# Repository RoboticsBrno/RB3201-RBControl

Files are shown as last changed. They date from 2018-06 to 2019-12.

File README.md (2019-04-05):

# RB3201-RBControl

[[English version follows]](#english-version)

RB3201-RBControl (RBC) - univerzální deska pro stavbu hobby robotů.

Licence: [CC BY-SA 4.0](https://creativecommons.org/licenses/by-sa/4.0/?)

Arduino knihovna: [RB3201-RBControl-library](https://github.com/RoboticsBrno/RB3201-RBControl-library) ([PlatformIO](https://platformio.org/lib/show/5532/RB3201-RBControl))

Jde v podstatě o shield k vývojovému kitu [ESP32-DevKitC](https://www.espressif.com/en/products/hardware/esp32-devkitc/overview), který má dva hlavní cíle:

- umožnit snadné připojení velkého množství různých periférií (motory s enkodéry, serva, senzory...)
- rozšířit počet pinů desky ESP32 

## Hlavní vlastnosti

- současně ovládat až 8 DC motorů (1,5 A trvale, 2A špičkově každý) a obsluhovat 8 enkodérů pro tyto motory
- po osazení spínanými zdroji napájet a ovládat 4 serva nebo 8 mikroserv
- vyvedená I2C sběrnice - celkem 6x (4x s 3,3 V a 2x s 5 V logickou úrovní)
- expandér pinů, který je připojený přes I2C a obsluhuje další dva porty A,B po 8 pinech (celkem dalších 16 pinů) 
- tři tlačítka, 4 LED a piezo
- připravena ochrana proti přepólování a podvybití

## Rozšiřující moduly

### Motor enkodér

DPS jako enkodér na [upravené levné čínské motory s magnetem](https://mickoflus.cz/guide.html#motor-magnet)

- [Schema](docs/RB3201-RBControl_MotorEncoder_v1.1_schema.png)
- [Board](docs/RB3201-RBControl_MotorEncoder_v1.1_board.png)

### Lego konektor

- [LegoConnectorX1A - Schema](docs/RB3201-RBControl_LegoConnectorX1A_v1.0_schema.png)
- [LegoConnectorX1A - Board](docs/RB3201-RBControl_LegoConnectorX1A_v1.0_board.png)
- [LegoConnectorX1B - Schema](docs/RB3201-RBControl_LegoConnectorX1B_v1.0_schema.png)
- [LegoConnectorX1B - Board](docs/RB3201-RBControl_LegoConnectorX1B_v1.0_board.png)
- [LegoConnectorX2 - Schema](docs/RB3201-RBControl_LegoConnectorX2_v1.0_schema.png)
- [LegoConnectorX2 - Board](docs/RB3201-RBControl_LegoConnectorX2_v1.0_board.png)

# English Version

RB3201-RBControl (RBC) is a universal controller for hobby robots.

License: [CC BY-SA 4.0](https://creativecommons.org/licenses/by-sa/4.0/?)

Arduino library: [RB3201-RBControl-library](https://github.com/RoboticsBrno/RB3201-RBControl-library) ([PlatformIO](https://platformio.org/lib/show/5532/RB3201-RBControl))

The board is a shield for [ESP32-DevKitC](https://www.espressif.com/en/products/hardware/esp32-devkitc/overview) with the following two main functions:

- the board allows connecting a variety of peripherals (DC motors with encoders, RC servo motors, sensors, etc...)
- it expands the ESP32 GPIOs.

## Main Features

- it can control up to 8 DC motors (1.5 A average, 2 A peak for each motor), possibly with an encoder for each motor;
- after populating switching power supplies, it can power and control 4 servo motors or 8 micro servo motors;
- there are I2C headers for connection up to 6 peripherals (4x 3.3V, 2x 5V);
- there is an I2C GPIO expander, which adds two ports (A and B), 8 GPIOs each;
- three push buttons, four LEDs and a piezo buzzer built-in;
- reverse polarity and over-discharge protection.

## Expanding modules

### MotorEncoder

PCB encoder for dirty cheap Chinese DC motors with encoders.

- [Schema](docs/RB3201-RBControl_MotorEncoder_v1.1_schema.png)
- [Board](docs/RB3201-RBControl_MotorEncoder_v1.1_board.png)

### LegoConnector

- [LegoConnectorX1A - Schema](docs/RB3201-RBControl_LegoConnectorX1A_v1.0_schema.png)
- [LegoConnectorX1A - Board](docs/RB3201-RBControl_LegoConnectorX1A_v1.0_board.png)
- [LegoConnectorX1B - Schema](docs/RB3201-RBControl_LegoConnectorX1B_v1.0_schema.png)
- [LegoConnectorX1B - Board](docs/RB3201-RBControl_LegoConnectorX1B_v1.0_board.png)
- [LegoConnectorX2 - Schema](docs/RB3201-RBControl_LegoConnectorX2_v1.0_schema.png)
- [LegoConnectorX2 - Board](docs/RB3201-RBControl_LegoConnectorX2_v1.0_board.png)

## Schema ([PDF](docs/RB3201-RBControl_MainBoard_v1.2_schema.pdf))

Logic
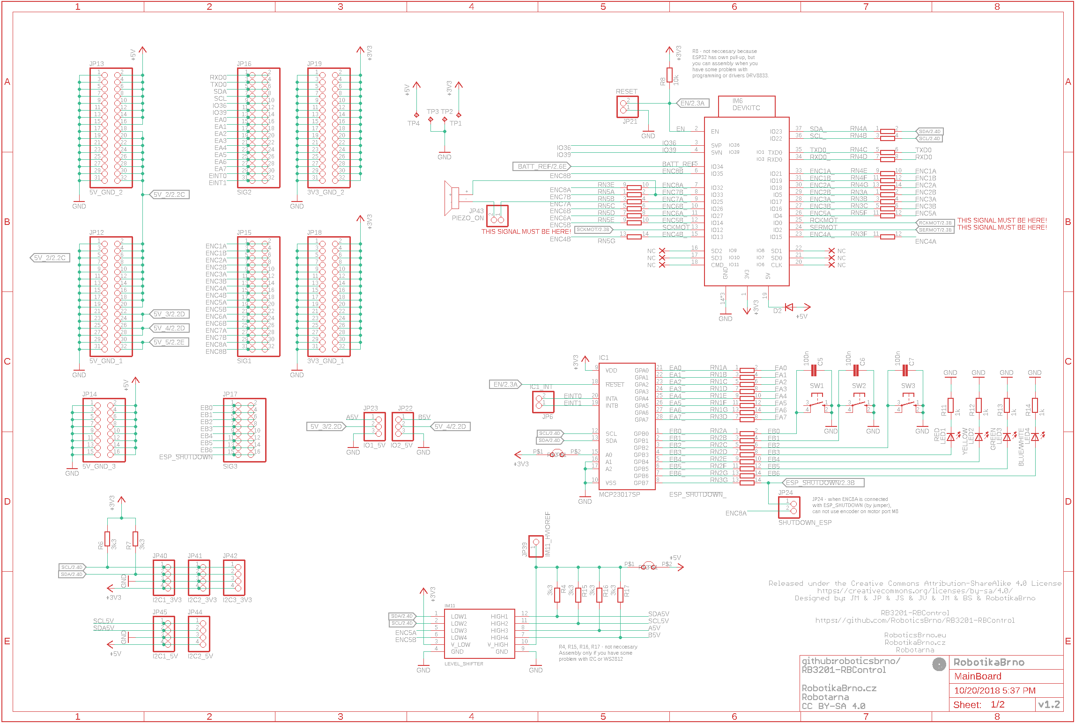
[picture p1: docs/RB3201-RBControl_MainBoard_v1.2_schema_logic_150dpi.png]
RB3201-RBControl - schema logic


Power
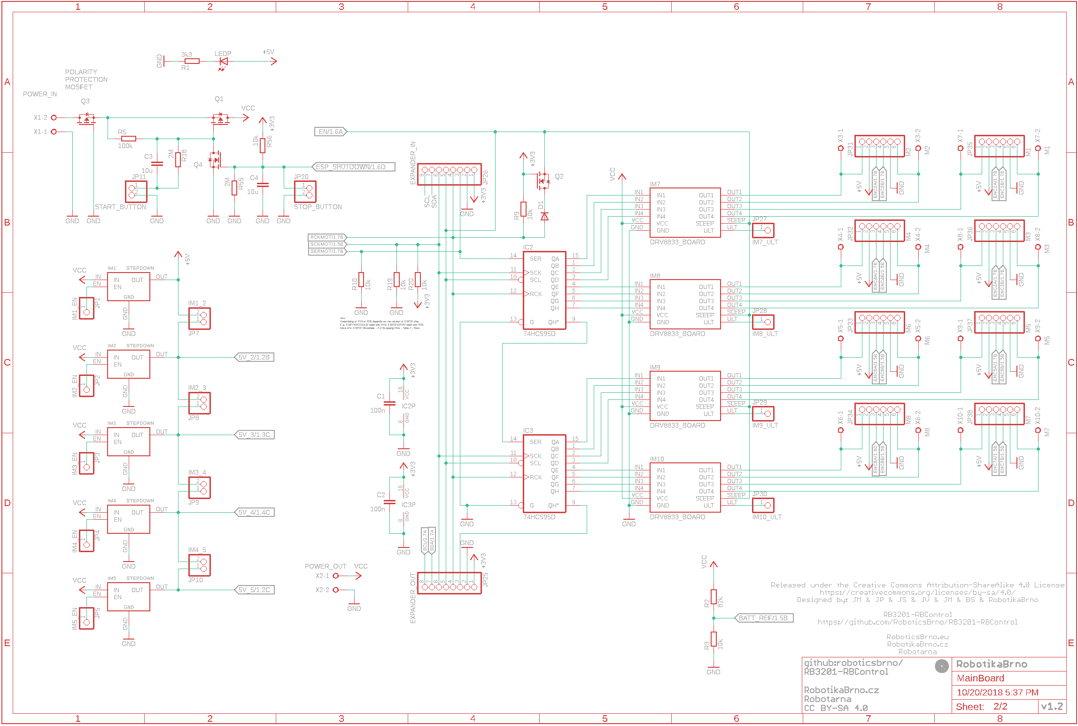
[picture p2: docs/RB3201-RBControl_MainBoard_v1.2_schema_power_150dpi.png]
RB3201-RBControl - schema power


## PCB ([PDF](docs/RB3201-RBControl_MainBoard_v1.2_board.pdf))

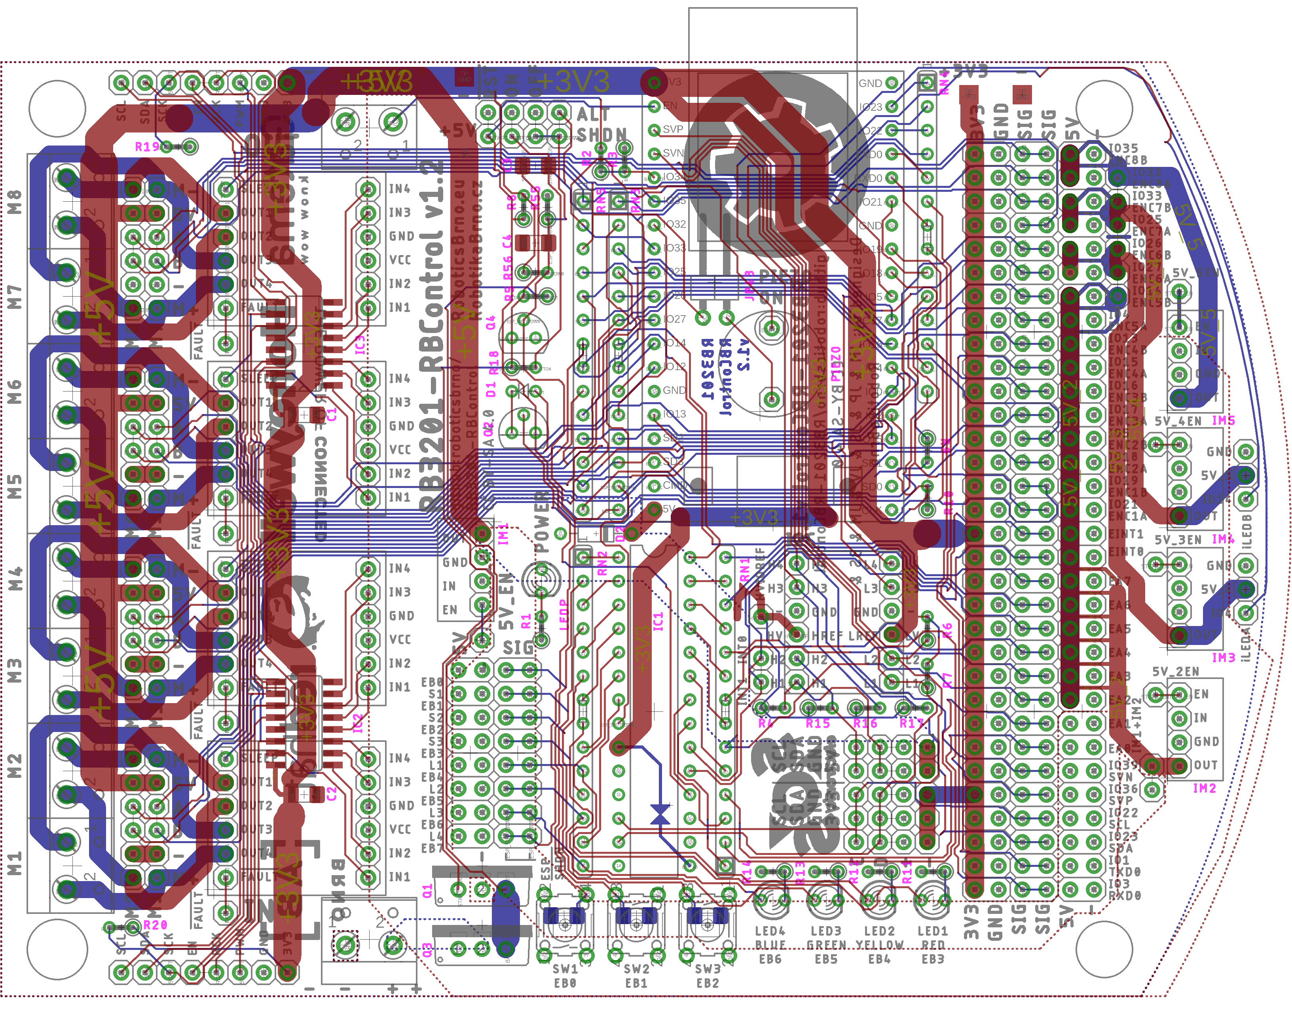
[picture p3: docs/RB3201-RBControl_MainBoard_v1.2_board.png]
RB3201-RBControl - PCB


## Photos

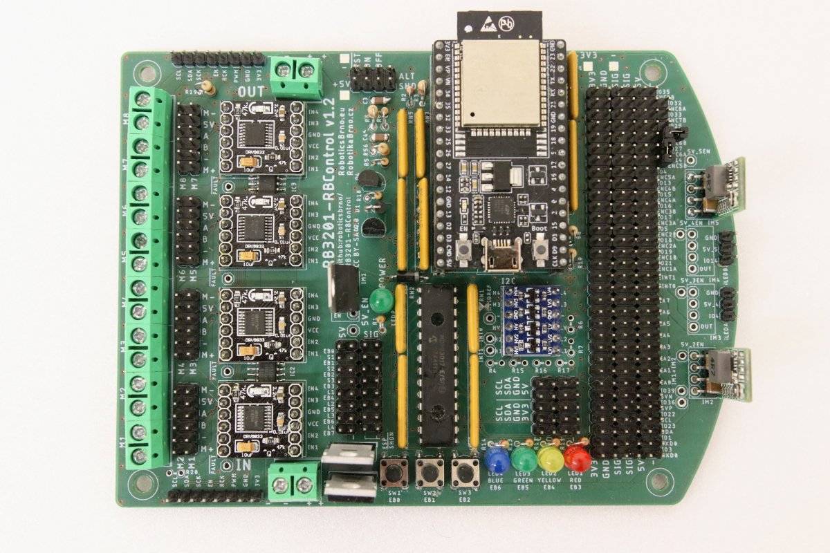
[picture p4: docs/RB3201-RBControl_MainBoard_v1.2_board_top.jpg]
RB3201-RBControl - PCB photo - top


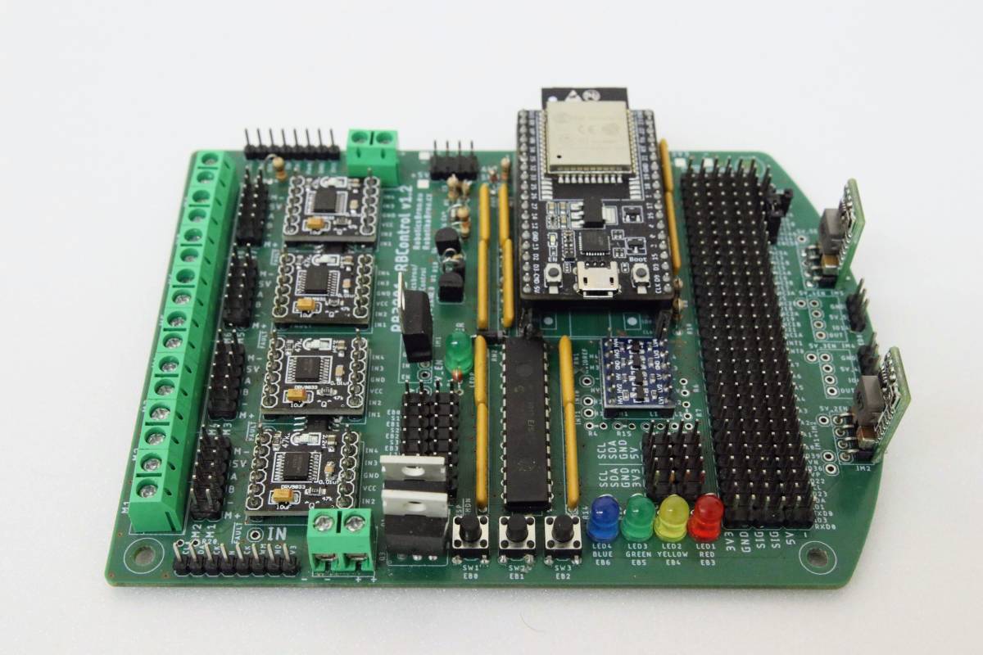
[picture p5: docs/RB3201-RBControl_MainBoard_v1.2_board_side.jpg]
RB3201-RBControl - PCB photo - side


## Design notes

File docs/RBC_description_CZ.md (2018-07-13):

# Vlastnosti desky RB3201-RBControl

## Určení a cíl

RB3201 - RBControl (RBC) je univerzální deska pro stavbu hobby robotů. Jde v podstatě o shield k desce 
 [ESP32 dev kit](https://www.espressif.com/en/products/hardware/esp32-devkitc/overview), který má dva hlavní cíle: rozšířit počet pinů desky ESP32 a umožnit snadné připojení velkého množství různých periférií. 

## Hlavní vlastnosti 

Deska RBC umožňuje současně ovládat až 8 DC motorů (1,5 	  A trvale, 2A špičkově každý). Dále umí po osazení spínanými zdroji napájet a ovládat 4 serva nebo 8 mikroserv. Má vyvedenou I2C sběrnici celkem 6x na 3,3 	  V a 2x na 5 	  V. Dále je na desce expandér pinů, který je připojený na I2C a obsluhuje další dva porty A,B po 8 pinech. Na desce jsou vyvedená tři tlačítka, 4 LED a piezo. 

## Další vlastnosti 

Po osazení tranzistorem Q3 je deska chráněná proti přepólování. Přímo na desce je možné měřit reálné hodnoty napětí 3,3 	  V a
5 	  V rozvedených po desce. 

Čip ESP32 má 26 použitelných pinů, z toho 4 pouze vstupní. Přitom na dvou pinech je připojena sériová linka (používá se pro programování čipu přes USB), na dvou pinech je I2C, 3 piny jsou použity pro komunikaci s drivery pro motory, 1 pin měří napětí na baterii. Pro uživatele tedy zbývá 14 pinů. 

K RBC s ESP32 je možné připojit další RBC bez ESP32 a rozšířit tak počet periférií a počet ovládaných motorů. U motorů na připojené ovládané RBC desce nelze použít enkodéry. Také je možné připojit k I2C místo 5 	  V libovolné externí napětí do cca 30 	  V  a provozovat I2C na tomto napětí. 

## Napájení

Napájení desky RBC je ideální ze dvou Li-On baterií, které dodávají asi 8 	  V a dostatečné proudy. K desce lze připojit napětí až do 10 	  V, připojení vyššího napětí neumožňují použité drivery pro motory. Do motorů je přiváděn signál PWM na napětí z baterie a 5 	  V napájení pro enkodéry.  

RBC si hlídá napětí na baterii a umí ho měřit do 10 	  V. 
V ESP32 je softwarově (v knihovně) nastavené napětí napájení 7,2 	  V, při kterém ESP32 vypne desku, aby nedošlo k podvybití baterie.  

Napětí 5 	  V pro desku může tvořit buď stabilizátor 7805 nebo spínaný zdroj.  
Z těchto 5 	  V se tvoří 3,3V na dalším stabilizátoru na desce ESP32 dev kit. Proto při napájení pouze z USB nebude fungovat rozvod 5 	  V na desce. 
Čip 7805 dává asi 1 	  A, většinu spotřebuje deska sama. Spínaný zdroj může dodávat 2 	  A. Celkem je možné na desku osadit 5 spínaných zdrojů.   

## Expandér

Expandér pinů pro ESP32 je k ESP32 připojen přes I2C. Funguje na 3,3 	  V, má dva porty A, B - každý má 8 pinů, port A je pro uživatele, port B je pro tlačítka, LED a vypínání desky, ale uživatel může port B také použít.

# Rozložení pinů na desce RBC a jejich vlastnosti

Pro snazší orientaci si otočte desku tak, aby oblouk na desce byl vpravo. 
Při popisu budeme postupovat zleva doprava a shora dolů. Poloha jednotlivých částí desky je vyznačena v souboru [RBC_image_description.png](https://github.com/RoboticsBrno/RB3201-RBControl/blob/master/docs/RBC_image_description.png).

1. Svorkovnice pro připojení DC motorů 

2. Piny pro připojení motorů s enkodéry. Protože ESP32 má málo pinů, je potřeba si zjistit, které piny jsou použité pro enkodéry a nepoužívat je na něco jiného. 

3. Výstupní piny, slouží signálovému propojení s další deskou RBC. 

4. Výstupní napájení. Použije se v případě připojení další RBC desky jako vstupní napájení pro připojenou desku. 
 Piny SCL, SDA, GND, 3V3 lze použít i samostatně jako další I2C port.
 
5. Drivery pro DC motory. Každý driver poskytuje PWM napájení pro dva motory. Každý driver má vyvedený pin 5A (FAULT), 
kde je možné měřit, jestli se nenachází v chybovém stavu. Každý driver má ochranu proti přetížení i přehřátí -> vypne se. 
Pod drivery jsou posuvné registry 5B, které generují signál pro motory podle pokynů z ESP32.

6. Vstupní piny, slouží signálovému propojení s řídící deskou RBC. 
  Piny SCL, SDA, GND, 3V3 lze použít i samostatně jako další I2C port.

7. Vstupní napájení z baterie nebo z řídící RBC desky. 

8. Jde o čtveřici jumperů, zleva doprava při propojení provedou následující: Reset RBC, zapnutí RBC, vypnutí RBC, vypnutí RBC v případě, že expandér není osazen nebo nefunguje.  

9. Stabilizátor 7805 (dodává cca 1 	  A, většinu z tohoto proudu spotřebuje RBC pro svůj provoz). Místo 7805 je možné osadit spínaný zdroj, který dodává cca 2 	  A.

10. Port B z expandéru. Zleva doprava jsou to piny: 5 	  V, GND, 2x signálový pin (ten stejný) na 3,3 	  V.
Na tomto portu jsou také připojená tlačítka, všechny LED a **vypínání desky (pin B7)**. Pozor, ve verzi 1.2 jsou popisy pinů posunuté o jeden pin dolů.

11. Tranzistor Q1 - zapíná desku. 

12.  Tranzistor Q3. Po osazení tranzistorem Q3 je deska chráněná proti přepólování.

13. Expandér pinů. 13A jsou piny pro sledování přerušení na portu A a portu B expandéru. 

14. Tlačítka S1, S2, S3. 

15. ESP32 dev kit 

16. Deska, která převádí signál I2C z 3,3 	  V na 5 	  V a signál pro připojení inteligentních LED a podobně - viz č. 17 a 23.

17. 2x I2C na 5 	  V

18. 3x I2C na 3,3 	  V

19. 4x LED 

20. Piny pro připojení periferií k ESP32. Součástí jsou piny portu A z expandéru (č. 20A). 
Zleva doprava: 3,3 	  V, GND, 2x signálový pin, 5 	  V, GND. Přitom piny 5 	  V jsou ve výchozím nastavení připojeny na spínané zdroje (č.21A-D, které samozřejmě musí být osazeny). Vyjímka je spodních 8 pinů, které jsou připojeny přímo ke stabilizátoru nebo spínanému zdroji (č. 9). Pokud chceme ostatní piny připojit na zdroj č. 9, musíme propojit jumpery 22A-D. 
Přitom piny tvoří kaskádu, tj. musím nedřív propojit jumper 22A, potom 22B atd. 

21. Místo pro osazení spínaných zdrojů (step-down): 21A, 21B, 21C, 1D. Každý zdroj má vyvedený tzv. enable-pin. 
Zdroje jsou ve výchozím stavu zapnuté a lze je  vypnout tak, že na enable-pin přivedu kabelem z jiného pinu potřebný signál. 

Na každý spínaný zdroj (step-down) je možné připojit jedno servo nebo dvě mikroserva. Piny jsou vyvedeny tak, aby bylo možné serva připojit přímo. Přitom zdroj 21D obsluhuje horní dva piny 5 	  V, zdroj 21C dva piny 5 	  V pod nimi, zdroj 21B opět dva piny 5 	  V pod nimi a zdroj 21A všechny zbývající piny 5 	  V kromě spodních osmi.

22. Jumpry pro připojení spínaných zdrojů z bodu 21, písmeno vždy odpovídá: 22A, 22B, 22C, 22D.

23. Signál pro inteligentní LED nebo podobné zařízení - piny na desce nejvíce vpravo (nejsou vyznačeny).

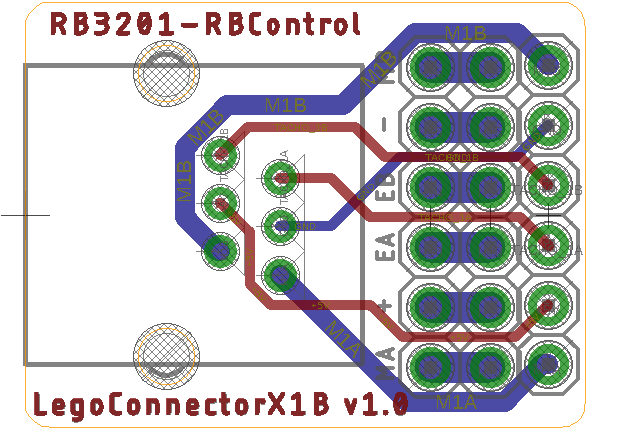
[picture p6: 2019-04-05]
docs/RB3201-RBControl_LegoConnectorX1B_v1.0_board.png

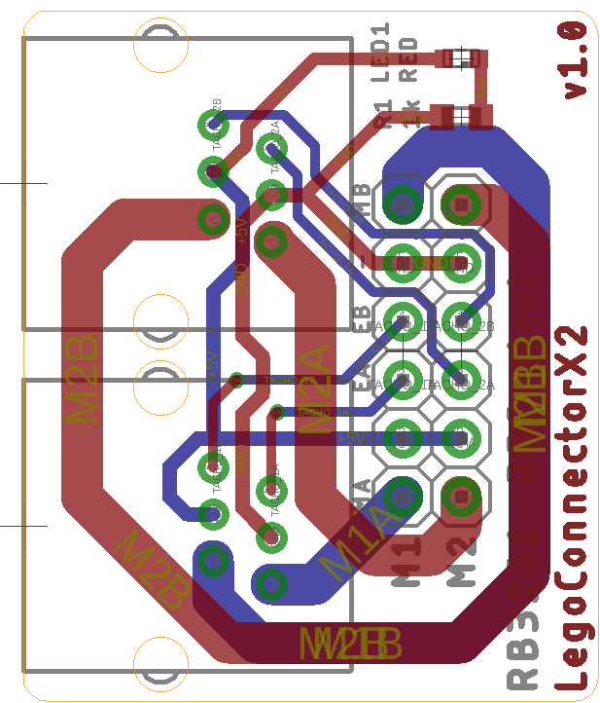
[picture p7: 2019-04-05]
docs/RB3201-RBControl_LegoConnectorX2_v1.0_board.png

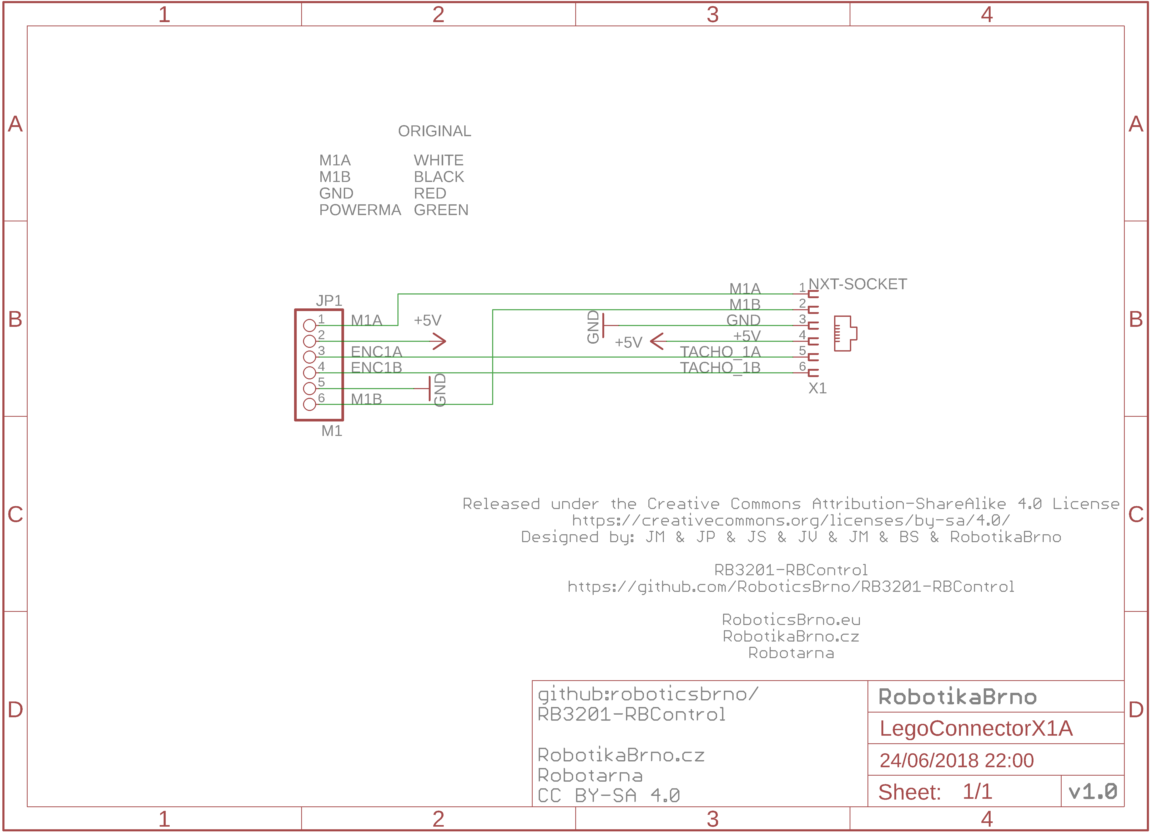
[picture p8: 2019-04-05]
docs/RB3201-RBControl_LegoConnectorX1A_v1.0_schema.png

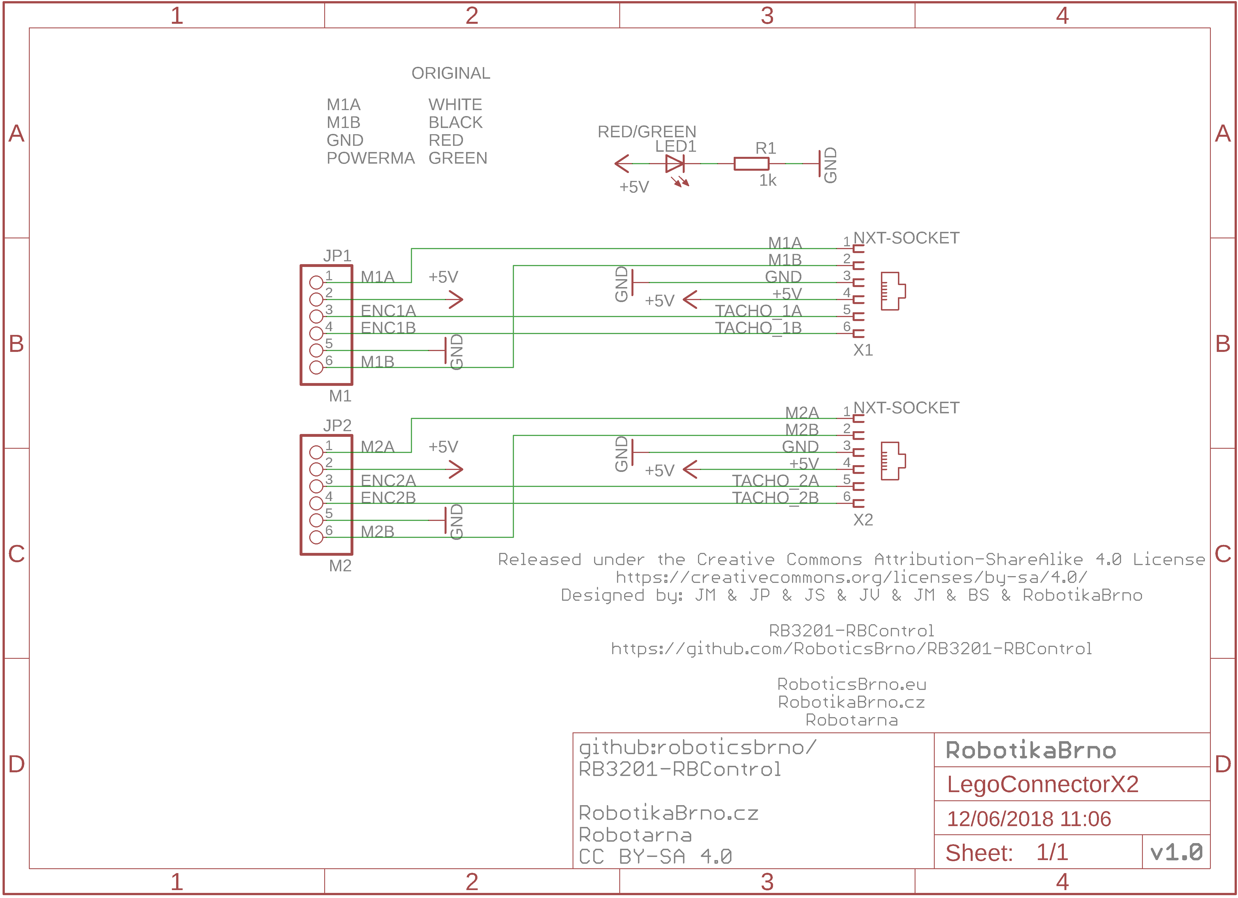
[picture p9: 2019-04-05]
docs/RB3201-RBControl_LegoConnectorX2_v1.0_schema.png

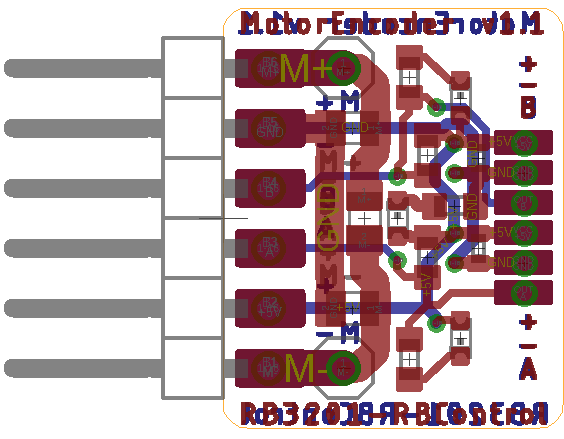
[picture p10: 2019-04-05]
docs/RB3201-RBControl_MotorEncoder_v1.1_board.png

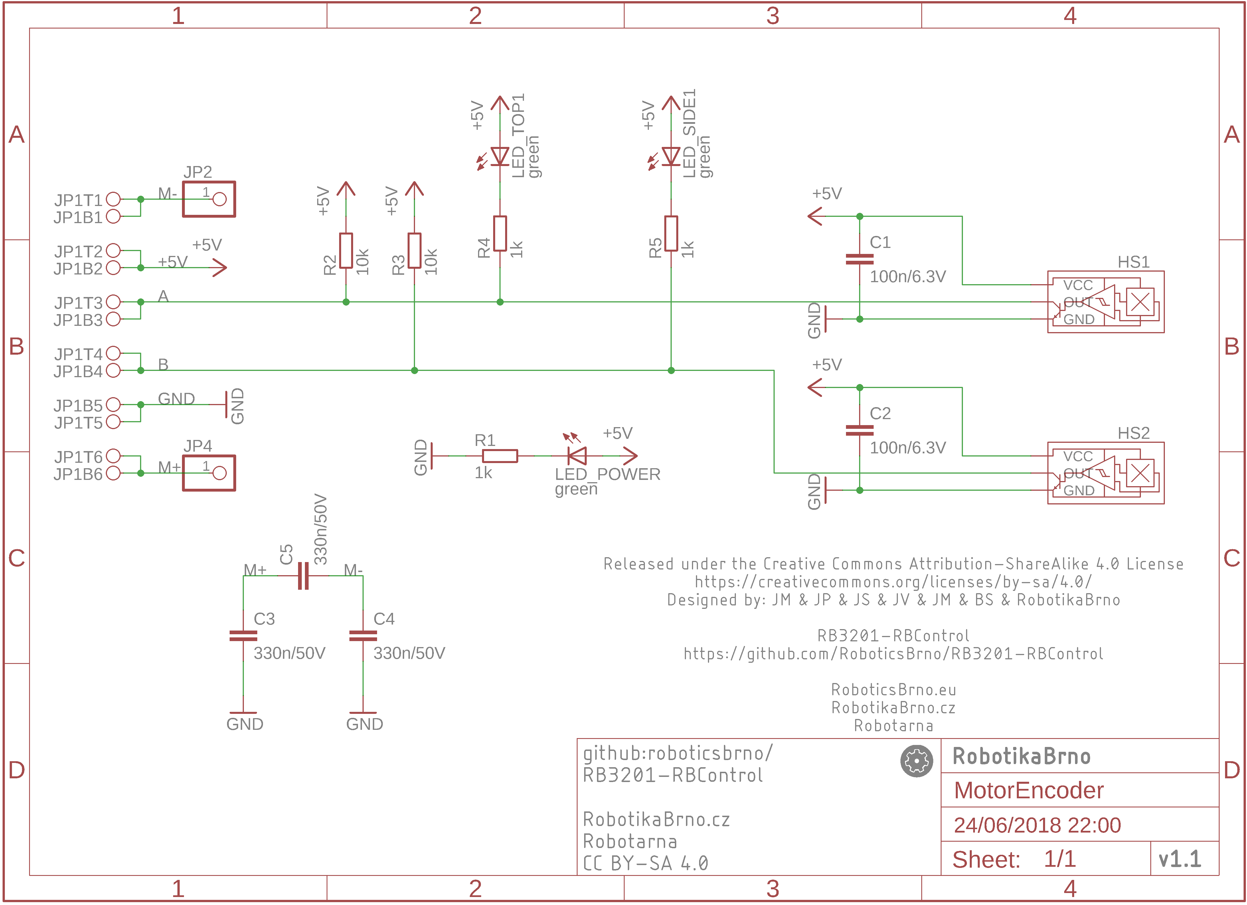
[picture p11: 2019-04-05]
docs/RB3201-RBControl_MotorEncoder_v1.1_schema.png

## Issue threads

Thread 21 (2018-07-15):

[CZ] Opravit rozteče u odporů pro LEDky

JarekParal, 2018-07-15:
Opravit rozteče u odporů pro LEDky tak, aby se dali nahradit rezistorovými sítěmi.

JarekParal, 2019-07-02:
Fix in MainBoard v1.4 (02048ede658323963773bc928ec73895d5127cfc)

Closed 2019-07-02.

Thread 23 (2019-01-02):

Fix labels of the 5V pinheads

JarekParal, 2019-01-02:
Change label `5V` to something more correct (e.g. `VIN`, `VSET`...). In this pinheads line is battery voltage from voltage regulator (`IM1-IM5`).

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
(need change on both side of pinheads)

JarekParal, 2019-07-02:
The label wasn't changed but there were added labels to pinheads (MainBoard v1.3 - 578f0731ebaf5753342217cab8a680f187f3a2c7):
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

Closed 2019-07-02.

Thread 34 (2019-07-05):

[CZ] BatteryPack: charger/dock deska

mkousal, 2019-07-05:
Deska obsahuje přebytečné díry vedle prokovených děr B2+, B1+, B2-, B1-
Jsou matoucí a mohlo by docházet k nechtěné záměně, byť nejsou prokovené

yaqwsx, 2019-07-05:
Problém s výrobou - podklady jsou OK.

Closed 2019-07-05.

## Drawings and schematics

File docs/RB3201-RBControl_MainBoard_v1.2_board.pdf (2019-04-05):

GND 1 1 | 1 | 1 1

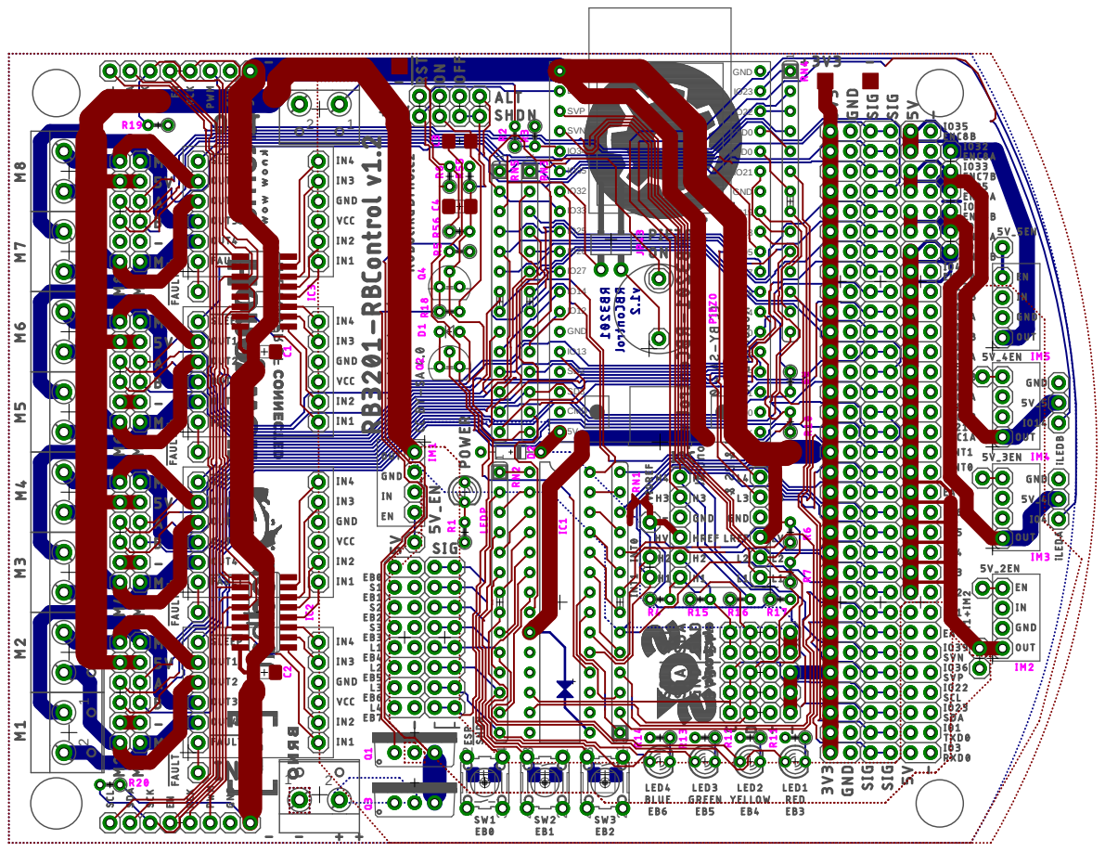
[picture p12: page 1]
SVP; SVN; RXD0; TXD0; GND; CLK; CMD

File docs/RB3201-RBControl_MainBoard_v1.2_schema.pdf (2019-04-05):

A

A

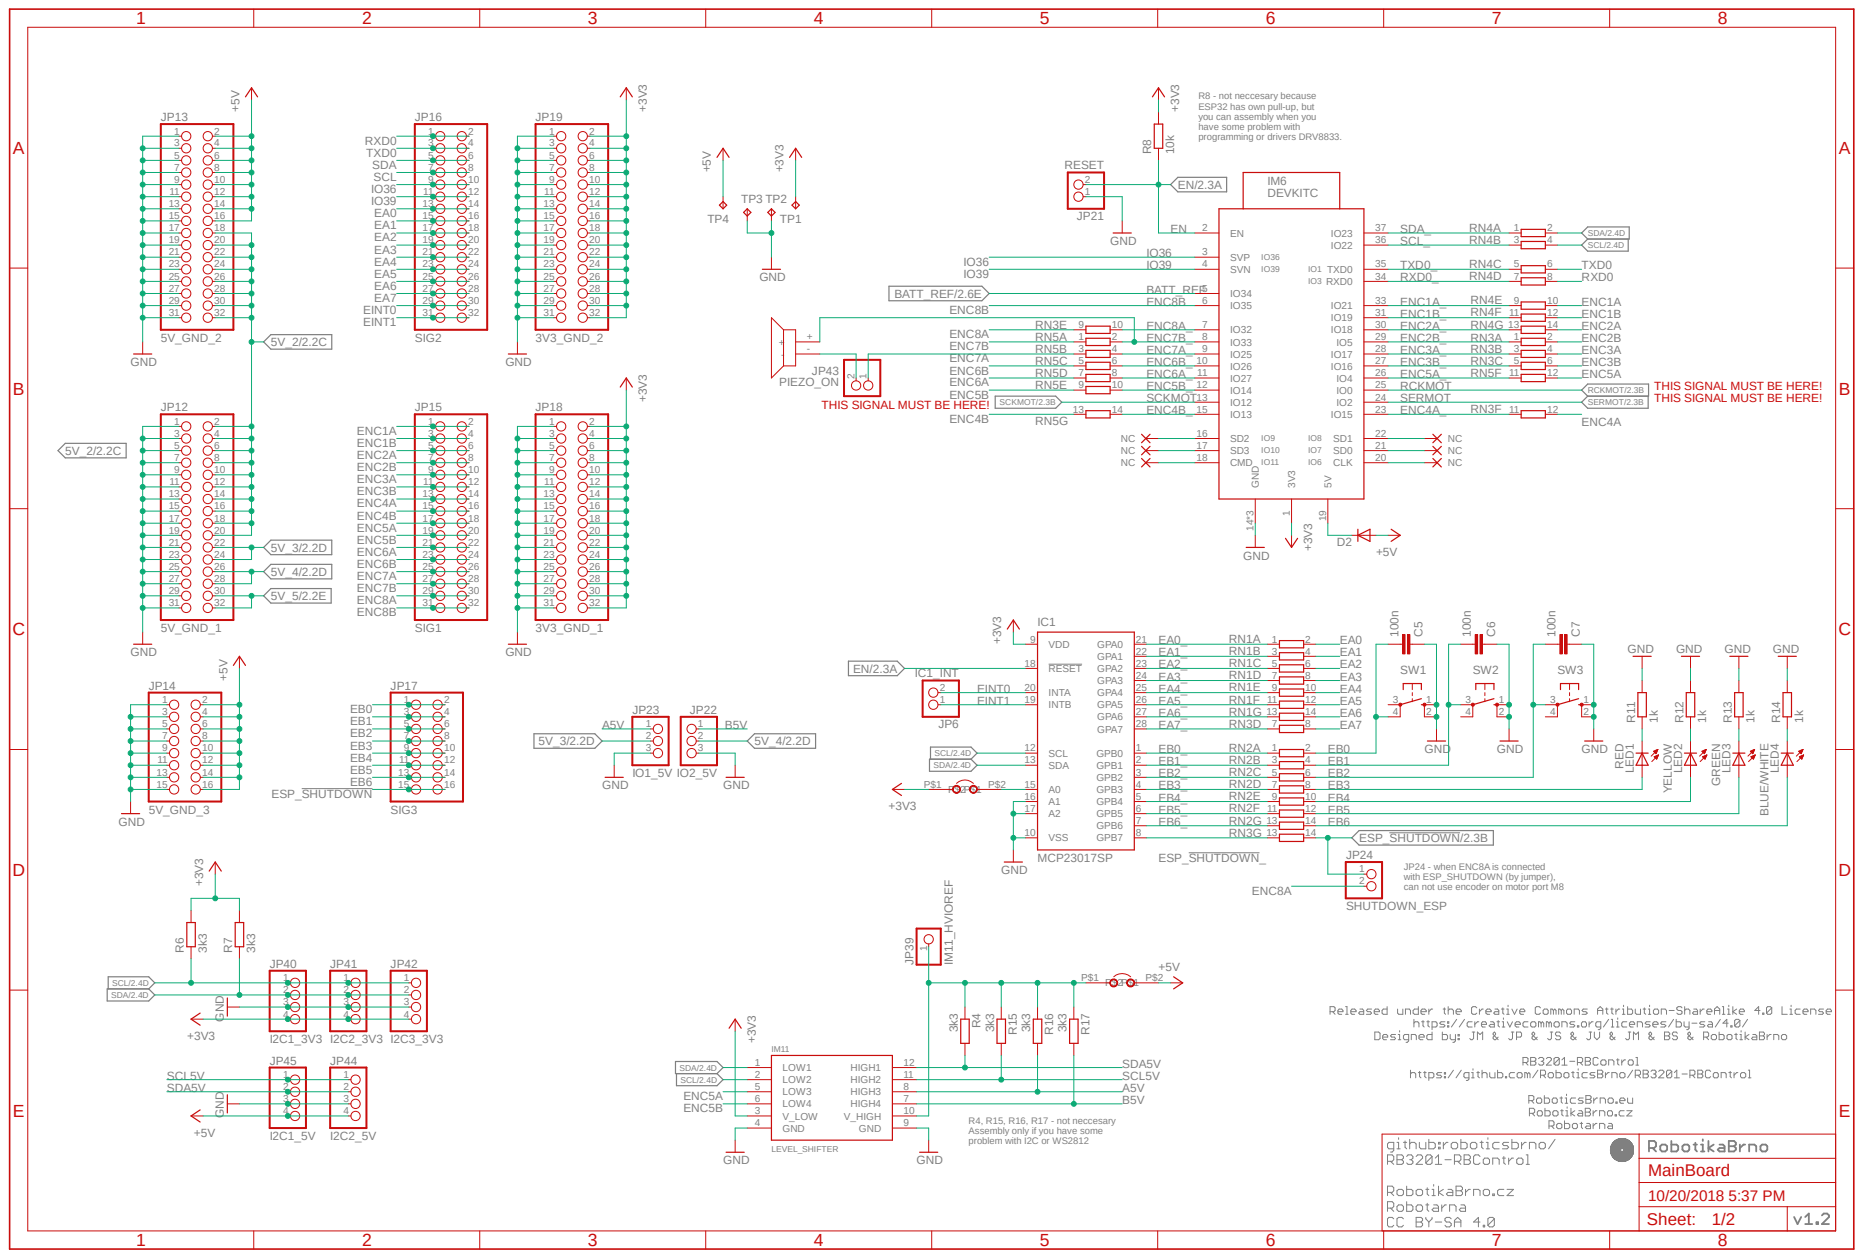
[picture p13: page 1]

R8 - not neccesary because
ESP32 has own pull-up, but
you can assembly when you
have some problem with
programming or drivers DRV8833.

THIS SIGNAL MUST BE HERE!

JP24 - when ENC8A is connected with ESP_SHUTDOWN (by jumper),
can not use encoder on motor port M8

R4, R15, R16, R17 - not neccesary
Assembly only if you have some
problem with I2C or WS2812

100n | 10k +3V³ 10k
EN/1.6A | SDA/1.7A SDA SCL/1.7A SCL

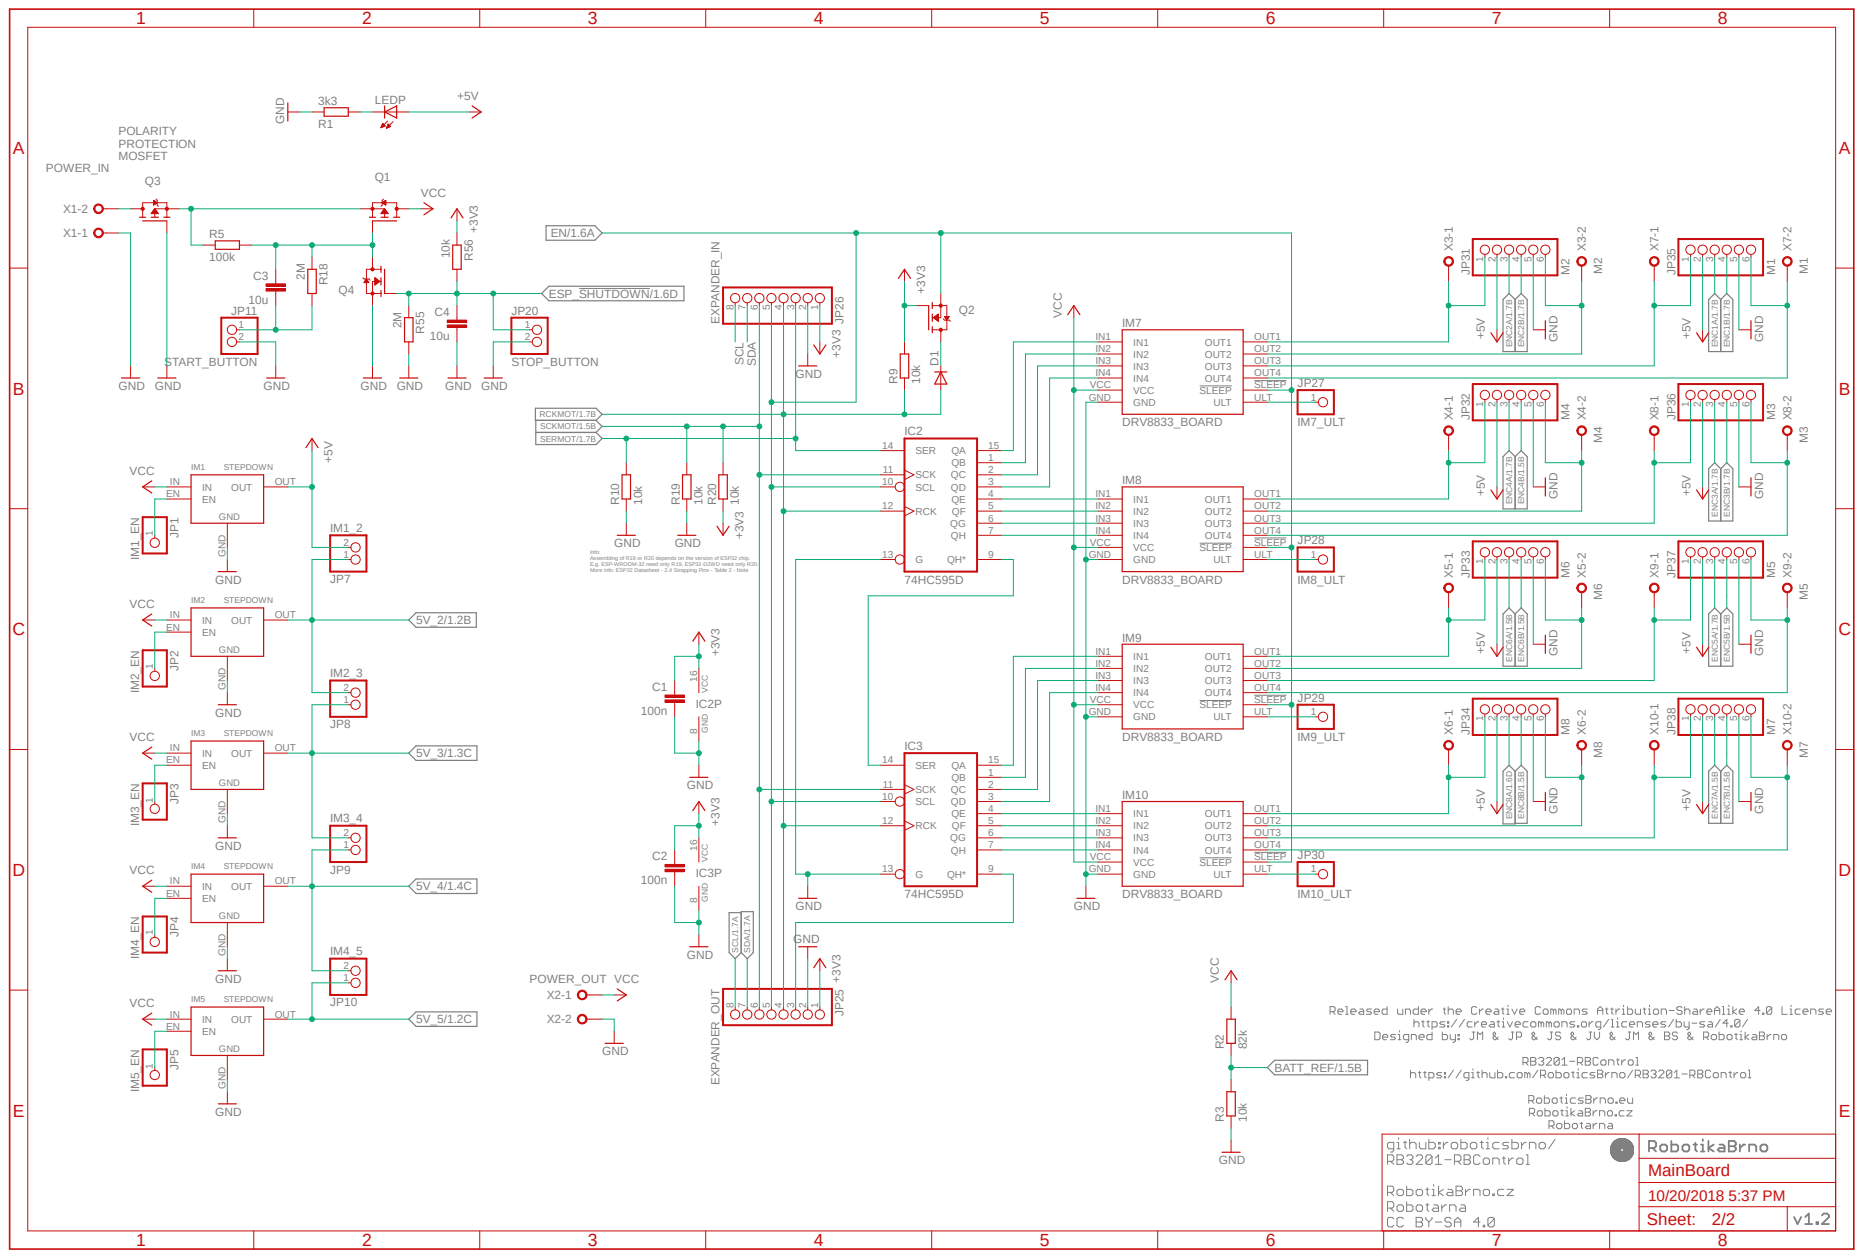
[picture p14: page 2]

Info:
Assembling of R19 or R20 depends on the version of ESP32 chip.
E.g. ESP-WROOM-32 need only R19, ESP32-D2WD need only R20.

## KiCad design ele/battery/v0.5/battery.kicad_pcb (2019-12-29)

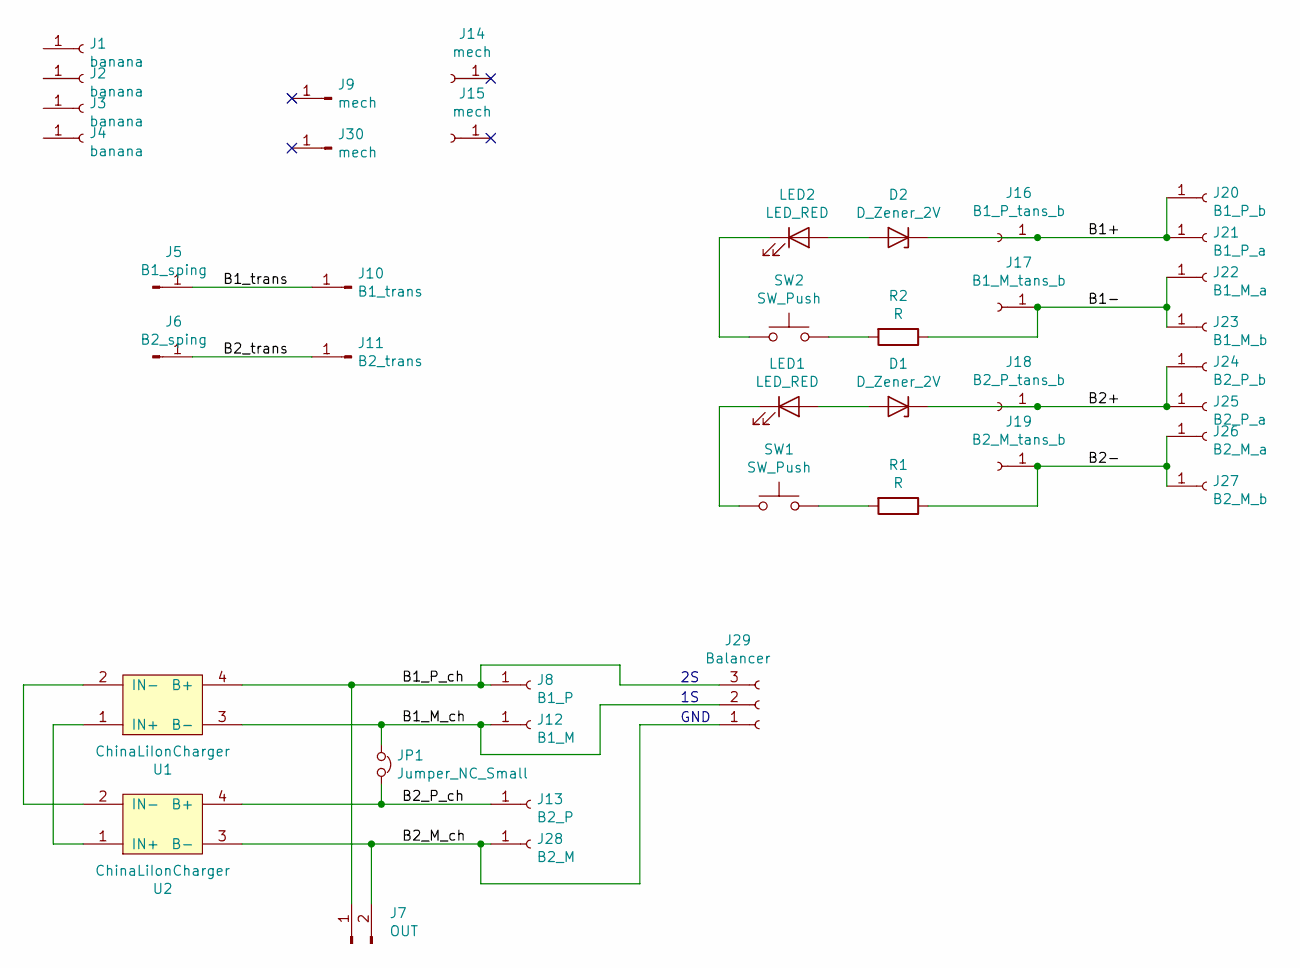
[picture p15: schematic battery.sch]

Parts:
D1, D2: D_Zener_2V; D_1206_3216Metric_Pad1.42x1.75mm_HandSolder
J1, J2, J3, J4: banana; banana_2mm_side
J5: B1_sping; battery_spring_contact
J6: B2_sping; battery_spring_contact
J7: OUT; 2_pads_5mm
J8: B1_P; banana_2mm_hole
J9, J30: mech; pad_3x5
J10: B1_trans; pad_2x3
J11: B2_trans; pad_2x3
J12: B1_M; banana_2mm_hole
J13: B2_P; banana_2mm_hole
J14, J15: mech; slot_1.8x5
J16: B1_P_tans_b; slot_1.8x2
J17: B1_M_tans_b; slot_1.8x2
J18: B2_P_tans_b; slot_1.8x2
J19: B2_M_tans_b; slot_1.8x2
J20: B1_P_b; banana_2mm_hole
J21: B1_P_a; banana_2mm_hole
J22: B1_M_a; banana_2mm_hole
J23: B1_M_b; banana_2mm_hole
J24: B2_P_b; banana_2mm_hole
J25: B2_P_a; banana_2mm_hole
J26: B2_M_a; banana_2mm_hole
J27: B2_M_b; banana_2mm_hole
J28: B2_M; banana_2mm_hole
J29: Balancer; PinSocket_1x03_P2.54mm_Horizontal
JP1: Jumper_NC_Small; power_solder_jumper
LED1, LED2: LED_RED; LED_1206_3216Metric_Pad1.42x1.75mm_HandSolder
R1, R2: R; R_1206_3216Metric_Pad1.42x1.75mm_HandSolder
SW1, SW2: SW_Push; SW_SPST_EVQP0
U1, U2: ChinaLiIonCharger; LiOnCharger

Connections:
/B1+: D2.1 (K), J16.1, J20.1, J21.1
/B1-: J17.1, J22.1, J23.1, R2.1
/B1_M_ch: J12.1, J29.2, JP1.1, U1.3 (B-)
/B1_P_ch: J7.1, J8.1, J29.3, U1.4 (B+)
/B1_trans: J5.1, J10.1
/B2+: D1.1 (K), J18.1, J24.1, J25.1
/B2-: J19.1, J26.1, J27.1, R1.1
/B2_M_ch: J7.2, J28.1, J29.1, U2.3 (B-)
/B2_P_ch: J13.1, JP1.2, U2.4 (B+)
/B2_trans: J6.1, J11.1
unnamed: D1.2 (A), LED1.2 (A)
unnamed: D2.2 (A), LED2.2 (A)
unnamed: LED1.1 (K), SW1.1
unnamed: LED2.1 (K), SW2.1
unnamed: R1.2, SW1.2
unnamed: R2.2, SW2.2
unnamed: U1.1 (IN+), U2.1 (IN+)
unnamed: U1.2 (IN-), U2.2 (IN-)

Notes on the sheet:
GND

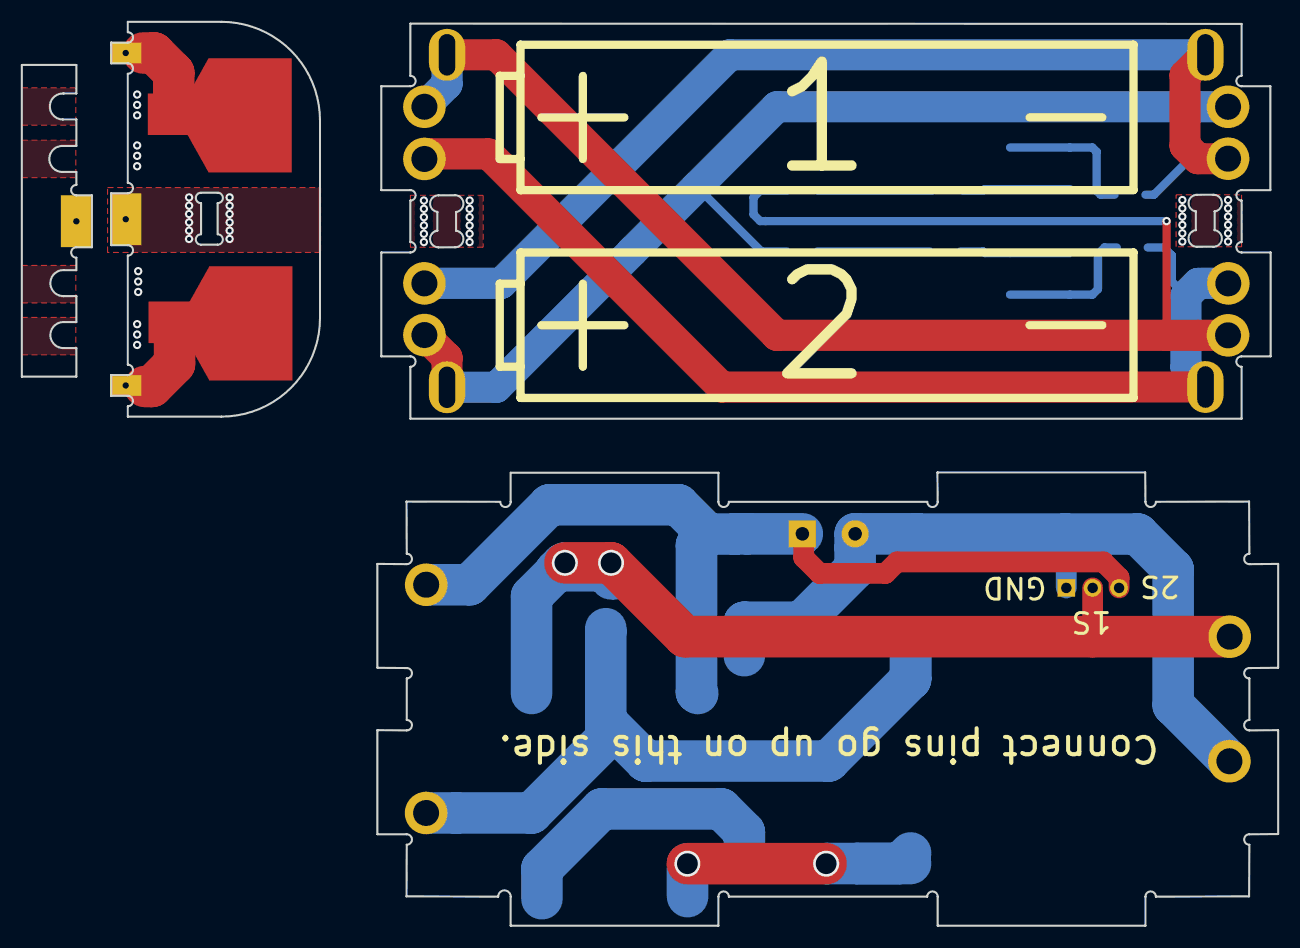
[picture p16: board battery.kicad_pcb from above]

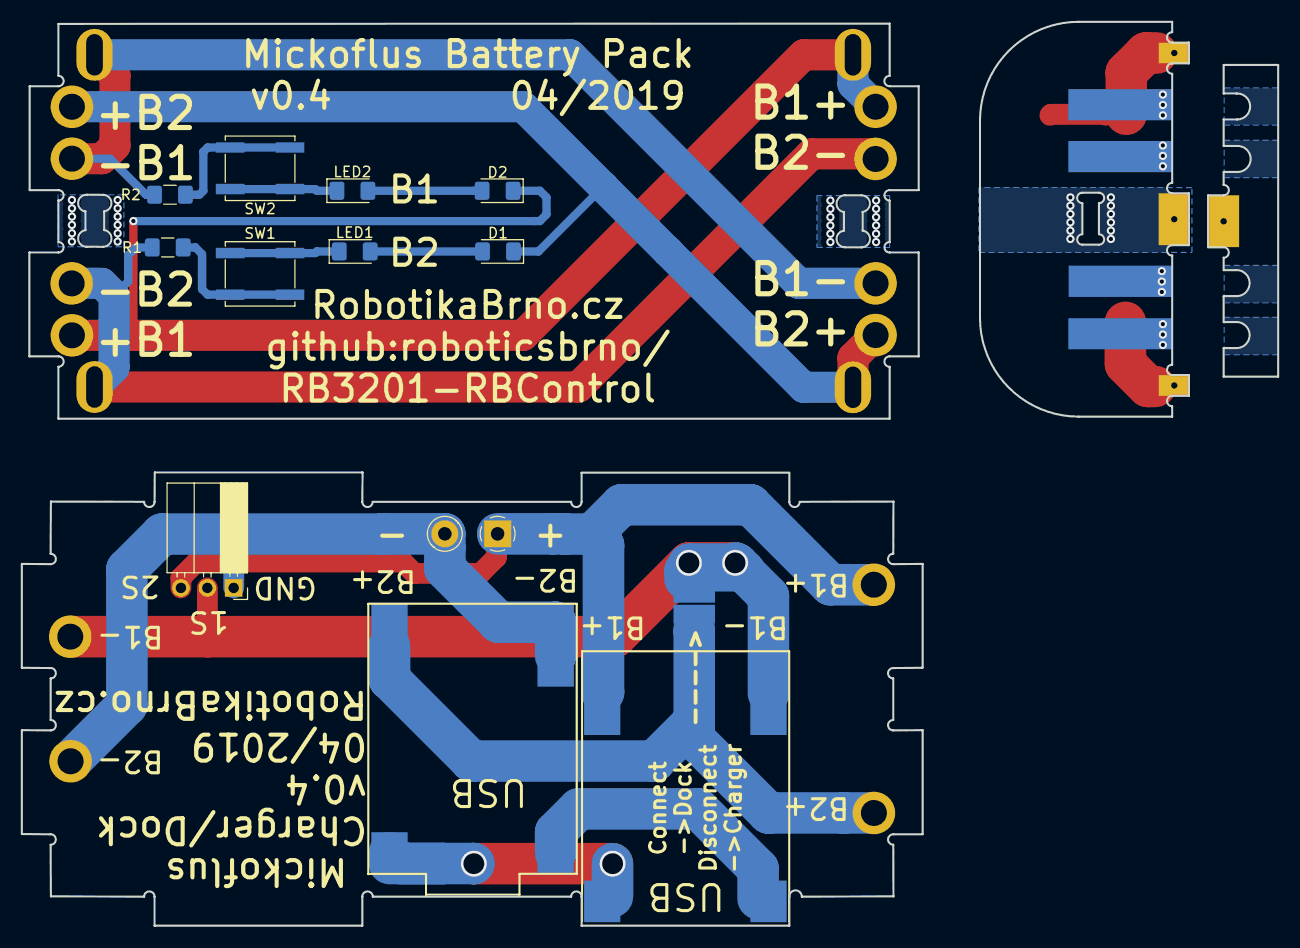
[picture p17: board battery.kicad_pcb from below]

Board: 2 copper layers, 120.9 x 87.0 mm, 39 parts (17 on the bottom side), 18 nets.

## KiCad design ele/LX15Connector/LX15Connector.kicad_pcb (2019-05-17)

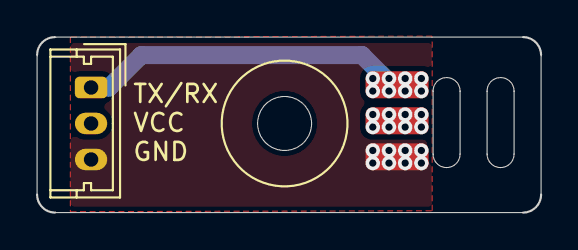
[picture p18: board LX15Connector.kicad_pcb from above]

Board: 2 copper layers, 28.0 x 9.8 mm, 3 parts (0 on the bottom side), 3 nets.

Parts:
H1: MountingHole; MountingHole_3mm
J1: Pads; 3_wire_pads
J2: Servo; Molex_Micro-Latch_53253-0370_1x03_P2.00mm_Vertical

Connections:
/GND: J1.3, J2.3
/TXRX: J1.1, J2.1
/VCC: J1.2, J2.2

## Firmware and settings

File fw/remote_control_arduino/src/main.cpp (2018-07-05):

#include <Arduino.h>
#include "BluetoothSerial.h"

#if !defined(CONFIG_BT_ENABLED) || !defined(CONFIG_BLUEDROID_ENABLED)
#error Bluetooth is not enabled! Please run `make menuconfig` to and enable it
#endif

#include <i2s_parallel.h>
#include <format.h>
using fmt::print;


#include "hexdump.h"
#include "serialpcm.hpp"

#define ATOMS_NO_EXCEPTION
#include "avakar.h"

 void printPwm(int pwmi, const SerialPCM::value_type & pwm) {
     printf("pwm[%i] = %3i \n", pwmi, pwm);
 }

#define PRINT_WARNING(x) do {Serial.print("[Warning] "); Serial.println(x);} while(false)

class Joystick {   
    int m_axe[4] = {0};
    int m_buttons = 0;
    atoms::AvakarPacket packet;

public:
    bool onByte(int byte) {
        if(byte == -1) {
            PRINT_WARNING("Byte is -1. Check if you are not reading empty stream/Serial/...");
        }
        if(packet.push_byte(byte)) {
            if((packet.get_command() == 1) && (packet.size() == 9)) {
                for(int i = 0; i < 4; ++i) {
                    m_axe[i] = packet.get<int16_t>(i*2);
                }
                m_buttons = packet.get<uint8_t>(8);
                packet.clear();
                return true;
            } else {
                PRINT_WARNING("Unknown packet");
            }
        }
        return false;
    }

    int axe(int index) {
        if(index < 0 || index > 3) {
            PRINT_WARNING("axe index - out of range");
            return 0;
        }
        return m_axe[index];
    }

    int buttons() {
        return m_buttons;
    }

    bool button(int index) {
        if(index < 0 || index > 7) {
            PRINT_WARNING("button index - out of range");
            return false;
        }
        return m_buttons & (1 << index);
    }
};

// channels
// M1: 12, 13
// M2: 2, 3 
// M3: 8, 9
// M4: 14, 15    
// M5: 4, 5
// M6: 10, 11
// M7: 1, 2
// M8: 6, 7 
// M: 12, 13, 2, 3, 8, 9, 14, 15, 4, 5, 10, 11, 1, 2, 6, 7

int clamp(int val, int min, int max) {
    if(val < min) {
        return min;
    } else if (val > max) {
        return max;
    }
    return val;
}

void motorPwmSet(SerialPCM::value_type & pwm0, SerialPCM::value_type & pwm1, int power) {
    power = clamp(power, -255, 255);
    
    if(power > 0) {
        pwm0 = 0;
        pwm1 = power;
    } else {
        pwm0 = -power;
        pwm1 = 0;
    }
}

BluetoothSerial SerialBT;

void setup() {
    Serial.begin(115200);
    print(Serial, "\n\nMickoflus BT control test\n\t{} {}\n\n", __DATE__, __TIME__);

    if (!SerialBT.begin("Mickoflus01")) { //Bluetooth device name
        print(Serial, "!!! Bluetooth initialization failed!\n");
    }

    const int channels = 16;
    // After uncomment get exception in terminal from ESP32 
    SerialPCM pwm {channels, {2}, 0, 12};
    // int pwmi = 0;
    // for (int i = 0; i != channels; ++i)
    //     pwm[i] = 0;
    // pwm.update();

    Joystick joy;
    int lmot, rmot;
    int axe[2];

    for (;;) {
        micros(); // update overflow
        if (SerialBT.available()) {
            char c = SerialBT.read();
            //Serial.write(c);
            
            if(joy.onByte(c)) {         
                axe[0] = joy.axe(0) >> 7;
                axe[1] = joy.axe(1) >> 7; 
                lmot = axe[0] + axe[1];
                rmot = axe[0] - axe[1];

                motorPwmSet(pwm[12], pwm[13], lmot);
                motorPwmSet(pwm[2], pwm[3], rmot);
                pwm.update();

                print(Serial, "{:3} {:3}\n", lmot, rmot);
            }
        }
    }
}

void loop() {}

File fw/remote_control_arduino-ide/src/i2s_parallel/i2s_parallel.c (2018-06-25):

// Copyright 2017 Espressif Systems (Shanghai) PTE LTD
//
// Licensed under the Apache License, Version 2.0 (the "License");
// you may not use this file except in compliance with the License.
// You may obtain a copy of the License at
//
//     http://www.apache.org/licenses/LICENSE-2.0
//
// Unless required by applicable law or agreed to in writing, software
// distributed under the License is distributed on an "AS IS" BASIS,
// WITHOUT WARRANTIES OR CONDITIONS OF ANY KIND, either express or implied.
// See the License for the specific language governing permissions and
// limitations under the License.

#include <stdio.h>
#include <stdint.h>
#include <stddef.h>
//#include <string.h>

#include "freertos/FreeRTOS.h"
#include "freertos/task.h"
#include "freertos/semphr.h"
#include "freertos/queue.h"

#include "soc/i2s_struct.h"
#include "soc/i2s_reg.h"
#include "driver/periph_ctrl.h"
#include "soc/io_mux_reg.h"
#include "rom/lldesc.h"
#include "esp_heap_caps.h"
#include "i2s_parallel.h"
#include "driver/gpio.h"

typedef struct {
    volatile lldesc_t *dmadesc_a, *dmadesc_b;
    int desccount_a, desccount_b;
} i2s_parallel_state_t;

static i2s_parallel_state_t *i2s_state[2]={NULL, NULL};

#define DMA_MAX (4096-4)

//Calculate the amount of dma descs needed for a buffer desc
static int calc_needed_dma_descs_for(i2s_parallel_buffer_desc_t *desc) {
    int ret=0;
    for (int i=0; desc[i].memory!=NULL; i++) {
        ret+=(desc[i].size+DMA_MAX-1)/DMA_MAX;
    }
    return ret;
}

static void fill_dma_desc(volatile lldesc_t *dmadesc, i2s_parallel_buffer_desc_t *bufdesc) {
    int n=0;
    for (int i=0; bufdesc[i].memory!=NULL; i++) {
        int len=bufdesc[i].size;
        uint8_t *data=(uint8_t*)bufdesc[i].memory;
        while(len) {
            int dmalen=len;
            if (dmalen>DMA_MAX) dmalen=DMA_MAX;
            dmadesc[n].size=dmalen;
            dmadesc[n].length=dmalen;
            dmadesc[n].buf=data;
            dmadesc[n].eof=0;
            dmadesc[n].sosf=0;
            dmadesc[n].owner=1;
            dmadesc[n].qe.stqe_next=(lldesc_t*)&dmadesc[n+1];
            dmadesc[n].offset=0;
            len-=dmalen;
            data+=dmalen;
            n++;
        }
    }
    //Loop last back to first
    dmadesc[n-1].qe.stqe_next=(lldesc_t*)&dmadesc[0];
    printf("fill_dma_desc: filled %d descriptors\n", n);
}

static void gpio_setup_out(int gpio, int sig, bool inv) {
    if (gpio==-1) return;
    PIN_FUNC_SELECT(GPIO_PIN_MUX_REG[gpio], PIN_FUNC_GPIO);
    gpio_set_direction(gpio, GPIO_MODE_DEF_OUTPUT);
    gpio_matrix_out(gpio, sig, inv, false);
}


static void dma_reset(i2s_dev_t *dev) {
    dev->lc_conf.in_rst=1; dev->lc_conf.in_rst=0;
    dev->lc_conf.out_rst=1; dev->lc_conf.out_rst=0;
}

static void fifo_reset(i2s_dev_t *dev) {
    dev->conf.rx_fifo_reset=1; dev->conf.rx_fifo_reset=0;
    dev->conf.tx_fifo_reset=1; dev->conf.tx_fifo_reset=0;
}

int i2snum(i2s_dev_t *dev) {
    return (dev==&I2S0)?0:1;
}

void i2s_parallel_setup(i2s_dev_t *dev, const i2s_parallel_config_t *cfg) {
    //Figure out which signal numbers to use for routing
    printf("Setting up parallel I2S bus at I2S%d\n", i2snum(dev));
    int sig_data_base, sig_wclk, sig_bclk;
    if (dev==&I2S0) {
        sig_data_base=I2S0O_DATA_OUT0_IDX;
        sig_wclk=I2S0O_WS_OUT_IDX;
        sig_bclk=I2S0O_BCK_OUT_IDX;
    } else {
        if (cfg->bits!=I2S_PARALLEL_BITS_16) {
            sig_data_base=I2S1O_DATA_OUT0_IDX;
        } else {
            //Because of... reasons... the 16-bit values for i2s1 appear on d8...d23
            sig_data_base=I2S1O_DATA_OUT8_IDX;
        }
        sig_wclk=I2S1O_WS_OUT_IDX;
        sig_bclk=I2S1O_BCK_OUT_IDX;
    }
    
    //Route the signals
    for (int x=0; x<cfg->bits; x++) {
        gpio_setup_out(cfg->gpio_bus[x], sig_data_base+x, false);
    }

    gpio_setup_out(cfg->gpio_wclk, sig_wclk, cfg->inv_wclk);
    gpio_setup_out(cfg->gpio_bclk, sig_bclk, cfg->inv_bclk);
    
    //Power on dev
    if (dev==&I2S0) {
        periph_module_enable(PERIPH_I2S0_MODULE);
    } else {
        periph_module_enable(PERIPH_I2S1_MODULE);
    }
    //Initialize I2S dev
    dev->conf.rx_reset=1; dev->conf.rx_reset=0;
    dev->conf.tx_reset=1; dev->conf.tx_reset=0;
    dma_reset(dev);
    fifo_reset(dev);
    
    //Enable LCD mode
    dev->conf2.val=0;
    dev->conf2.lcd_en=1;
    
    dev->sample_rate_conf.val=0;
    dev->sample_rate_conf.rx_bits_mod=cfg->bits;
    dev->sample_rate_conf.tx_bits_mod=cfg->bits;
    dev->sample_rate_conf.rx_bck_div_num=2;
    dev->sample_rate_conf.tx_bck_div_num=8;
    
    dev->clkm_conf.val=0;
    dev->clkm_conf.clka_en=0;
    dev->clkm_conf.clkm_div_a=1; //63
    dev->clkm_conf.clkm_div_b=1; //63
    dev->clkm_conf.clkm_div_num=cfg->clkspeed;
    
    dev->fifo_conf.val=0;
    dev->fifo_conf.rx_fifo_mod_force_en=1;
    dev->fifo_conf.tx_fifo_mod_force_en=1;
    dev->fifo_conf.rx_fifo_mod=1;
    dev->fifo_conf.tx_fifo_mod=1;
    dev->fifo_conf.rx_data_num=32; //Thresholds. 
    dev->fifo_conf.tx_data_num=32;
    dev->fifo_conf.dscr_en=1;
    
    dev->conf1.val=0;
    dev->conf1.tx_stop_en=0;
    dev->conf1.tx_pcm_bypass=1;
    
    dev->conf_chan.val=0;
    dev->conf_chan.tx_chan_mod=1;
    dev->conf_chan.rx_chan_mod=1;
    
    //Invert ws to be active-low... ToDo: make this configurable
    dev->conf.tx_right_first=1;
    dev->conf.rx_right_first=1;
    
    dev->timing.val=0;
    
    //Allocate DMA descriptors
    i2s_state[i2snum(dev)]=malloc(sizeof(i2s_parallel_state_t));
    i2s_parallel_state_t *st=i2s_state[i2snum(dev)];
    st->desccount_a=calc_needed_dma_descs_for(cfg->bufa);
    st->desccount_b=calc_needed_dma_descs_for(cfg->bufb);
    st->dmadesc_a=heap_caps_malloc(st->desccount_a*sizeof(lldesc_t), MALLOC_CAP_DMA);
    st->dmadesc_b=heap_caps_malloc(st->desccount_b*sizeof(lldesc_t), MALLOC_CAP_DMA);
    
    //and fill them
    fill_dma_desc(st->dmadesc_a, cfg->bufa);
    fill_dma_desc(st->dmadesc_b, cfg->bufb);
    
    //Reset FIFO/DMA -> needed? Doesn't dma_reset/fifo_reset do this?
    dev->lc_conf.in_rst=1; dev->lc_conf.out_rst=1; dev->lc_conf.ahbm_rst=1; dev->lc_conf.ahbm_fifo_rst=1;
    dev->lc_conf.in_rst=0; dev->lc_conf.out_rst=0; dev->lc_conf.ahbm_rst=0; dev->lc_conf.ahbm_fifo_rst=0;
    dev->conf.tx_reset=1; dev->conf.tx_fifo_reset=1; dev->conf.rx_fifo_reset=1;
    dev->conf.tx_reset=0; dev->conf.tx_fifo_reset=0; dev->conf.rx_fifo_reset=0;
    
    //Start dma on front buffer
    dev->lc_conf.val=I2S_OUT_DATA_BURST_EN | I2S_OUTDSCR_BURST_EN;
    dev->out_link.addr=((uint32_t)(&st->dmadesc_a[0]));
    dev->out_link.start=1;
    dev->conf.tx_start=1;
}
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

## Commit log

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2018-05-11 Added 5V supply (still no stabilizer from battery to 5V).
    [Mickoflus.brd, Mickoflus.sch]
2018-05-14 Major schematic improvements changed power supply names: VCC -> +3V3, V+ -> VCC fixed encoder power (+3V3 -> +5V) changed ESP pinout (disconnected internal memory pins, moved encoders out of bootstra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
    [Mickoflus.brd, Mickoflus.sch]
2018-05-16 Added voltage regulator and IO expander.
    [Mickoflus.brd, Mickoflus.sch]
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2018-05-17 Jarek's editations of the schematics.
    [Mickoflus.brd, Mickoflus.sch]
2018-05-21 ele: rename Mickoflus -> MainBoard
    [MainBoard.brd, MainBoard.sch]
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2018-05-21 ele: MotorBoard - fix the bug with the LEDs
    [MotorBoard.brd, MotorBoard.sch]
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2018-05-24 ele: convert project to Eagle 9, improve schema and pcb :), still need to finish schema Schema - clean, repair some things, renumber all component, add LEDs and buttons PCB - move all component to ne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
    [MainBoard.brd, MainBoard.sch]
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2018-05-26 ele: MainBoard - improve schematics and board: - fix bugs in net names - add Xref - add names to net without names - add values to pinheads for better routing - improve design of schema :-)
    [MainBoard.brd, MainBoard.sch]
2018-05-27 Add reverse polarity protection Power output terminal goes through power switch Connect ESP_SHUTDOWN jumper Change transistors package
    [MainBoard.brd, MainBoard.sch]
2018-05-27 ele: diode packages set to SOD123, add value to JP24
    [MainBoard.brd, MainBoard.sch]
2018-05-27 Add DRC rule file, modify default net class
    [MainBoard.brd, MainBoard.sch]
2018-05-27 ele: add OC_MOUSER to resistors arrays and try to route one DRV8833
    [MainBoard.brd, MainBoard.sch]
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2018-05-29 ele: Adjust mounting holes to metric grid, route motor connectors
    [MainBoard.brd]
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2018-05-30 ele: Fix typo in net name, move components around
    [MainBoard.brd, MainBoard.sch]
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2018-05-31 ele: Create main power polygons, flip power connectors
    [MainBoard.brd, MainBoard.sch]
2018-05-31 ele: Route some signals, make room for large currents
    [MainBoard.brd, MainBoard.sch]
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2018-06-06 ele: Return impossible headers, shrink board, route signals
    [MainBoard.brd, MainBoard.sch]
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2018-06-07 fixed ground from step-down converters
    [MainBoard.brd]
2018-06-07 fix airwires
    [MainBoard.brd]
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2018-06-07 ele: MainBoard - update name of board -> RB3201-RBControl
    [MainBoard.brd]
2018-06-07 ele: LegoConnector - add one text to top layer with name of board
    [LegoConnector.brd]
2018-06-07 ele: MotorEncoder - clone MotorBoard and start to make new PCB for encoders
    [MotorEncoder.brd, MotorEncoder.sch]
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2018-06-07 ele: rename LegoConnector -> LegoConnectorX2 and add board just with one RJ-12 connector - LegoConnectorX1
    [LegoConnectorX1.brd, LegoConnectorX1.sch, LegoConnectorX2.brd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]
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2018-06-12 ele: MainBoard - start work on v1.1 - make round corners (now just of left side)
    [MainBoard.brd, MainBoard.sch]
2018-06-12 ele: Corrected DRV8833 pinhead package.
    [MainBoard.brd, MainBoard.sch]
2018-06-12 ele: MainBoard - add description texts on PCB
    [MainBoard.brd, MainBoard.sch]
2018-06-13 ele: move power switch from GND to VCC (schematic only)
    [MainBoard.brd, MainBoard.sch]
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2018-06-17 ele: Fix layout on left side (motor drivers)
    [MainBoard.brd, MainBoard.sch]
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2018-06-18 ele: Square up holes and adjust to millimeter grid
    [MainBoard.brd]
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2018-06-19 ele: Modified tNames layer on the PCB design.
    [MainBoard.brd, MainBoard.sch]
2018-06-19 ele: MainBoard - update tNames layer, join one pinheads with nearest pinheads
    [MainBoard.brd]
2018-06-20 ele: MainBoard - move I2C pinheads to right due to USB cable for EPS32
    [MainBoard.brd, MainBoard.sch]
2018-06-20 ele: MainBoard - add text with description of PCB to layer bottom, remove RB logo
    [MainBoard.brd]
2018-06-20 ele: MainBoard - repair labels of IO pinheads
    [MainBoard.brd]
2018-06-20 ele: MainBoard - fix position, names, labels of motors pinheads and terminals block
    [MainBoard.brd, MainBoard.sch]
2018-06-20 ele: MainBoard - add diode to ESP32 +5V, add jumper for PIEZO ON/OFF
    [MainBoard.brd, MainBoard.sch]
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2018-06-20 ele: MainBoard - repair problem with pin IO12, change nets around piezo, change some names and labels
    [MainBoard.brd, MainBoard.sch]
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2018-06-20 ele: Added capacitors to buttons, added description to resistor arrays.
    [MainBoard.brd, MainBoard.sch]
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2018-06-21 ele: MainBoard - fix bug with stepdowns - reroute all routes from stepdowns (please check @cednik)
    [MainBoard.brd, MainBoard.sch]
2018-06-21 ele: MotorEncoder - clean labels in layer xName, xValue
    [MotorEncoder.brd]
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2018-06-23 ele: LegoConnectorX1 A/B - add type B Lego connector board for stacking type A (rename LegoConnectorX1 -> LegoConnectorX1A and add LegoConnectorX1B)
    [LegoConnectorX1A.brd, LegoConnectorX1A.sch, LegoConnectorX1B.brd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]
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2018-06-25 ele: MainBoard - fix TO92 transistors pinout, change diodes package from SMD to TH, some signals routing improvements, fix some labels position, change version to 1.2
    [MainBoard.brd, MainBoard.sch]
2018-06-25 fw: esp_serial_pwm_test - temporary remove fmt library from the project because compiling error
    [main.cpp, serialpcm.hpp]
2018-06-25 ele: MainBoard + MotorEncoder - set synchronization with Fusion
    [MainBoard.brd, MotorEncoder.brd]
2018-06-25 ele: MainBoard - change value of C3 - from 1uF to 10uF
    [MainBoard.brd, MainBoard.sch]
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2018-06-26 ele: MainBoard - add notes to schema with more description
    [MainBoard.brd, MainBoard.sch]
2018-06-26 ele: MainBoard - add and repair some labels (IO14, IO12 -> IO4, ...)
    [MainBoard.brd]
2018-06-26 ele: MainBoard - add partners logos to board and set spin for all texts
    [MainBoard.brd]
2018-06-26 ele: MainBoard - final version v1.2 - remove one surplus text
    [MainBoard.brd]
2018-06-26 ele: MainBoard - repair text with name of board in bottom layer
    [MainBoard.brd]
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2018-06-26 ele: LegoConnectorX1B - fix labels
    [LegoConnectorX1B.brd]
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2018-06-28 fw: remote_control_arduino - fix format library and serial PCM buffer descriptors initializing,
    [main.cpp, serialpcm.hpp]
2018-07-07 Using PCNT for counting quadrature signal pulses on correct mainBoard pins.
    [main.cpp]
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2018-07-11 motorEncoder secondary int32_t counter to prevent short term overflow.
    [main.cpp, motorEncoder.cpp]
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2019-01-02 ele: MainBoard.sch - repair version of the second sheet (v1.1 -> v1.2)
    [MainBoard.sch]
2019-01-02 README: add English version and change Czech text
    - add English version
    - add license CC BY-SA 4.0
    - add link to Arduino library
    - fix number of I2C connectors
2019-01-19 ele: battery - add battery pack in updated version
    Many improve from v0.1 (not commited):
    - improve width on route for higher current
    - fix bug with charge on charge/dock board and reroute it
    - add more text label
    [battery.kicad_pcb, battery.sch, bottom_panel.kicad_pcb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]
2019-04-04 ele: battery - add voltage/state LED indicators
    Use this buttons:
    - https://www.tme.eu/cz/details/tactb-64k-f/mikrospinace-tact/ninigi/
    - https://www.aliexpress.com/item/50PCS-LOT-SMD-4-4-1-5MM-7MM-4X4X1-5MM-7MM-5-2mm-x-5-2mm/32907185072.html
    [battery.kicad_pcb, battery.sch]
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2019-04-04 ele: battery - add missing KiCad footprint
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2019-04-05 ele: battery - improve battery indicator
    - rename LEDs and diodes
    - add missing routes on switch
    [battery.kicad_pcb, battery.sch]
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2019-04-05 ele: Fix symbol and footprint libraries
    [battery.kicad_pcb, battery.sch]
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2019-04-26 ele: Reroute board due to new LiOnCharger module
    - fix labels BAT+/- for charger pins
    [battery.kicad_pcb]
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2019-06-24 ele: MainBoard - version 1.3
    - Add warnings to special pins in silkscreen
    - Add +5V pinhead to power control connector
    - Add encoders power selectors
    - Add freewheeling diode
    - Add three connectors for LX-15D servo
    - Add pinhead to VCC
    - Fix the labels in silkscreen
    [MainBoard.brd, MainBoard.sch]
2019-07-02 Revert "in_out_board"
    This reverts commit 53cb209aade2c15d6b7790895eb1d7cb18b6ae1b.
    [in-out_board.brd, in-out_board.sch]
2019-07-02 ele: Restructured projects in ele folder to separate folders with version
    [LegoConnectorX1A.brd, LegoConnectorX1A.sch, LegoConnectorX1B.brd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]
2019-07-02 ele: MainBoard - version 1.4
    - Add large capacitors to main power
    - Add types and values for resistors, capacitors, diodes and transistors
    - Add Avast logo as parner of the RoboCamp/Robotarna
    - Swap position of C8 (large capacitor) and IM1 (power supply)
    - Move encoders voltage selectors away from pinheads
    - Change power polygons width to 0.4 mm
    - Change alt. shutdown pinhead (JP24) to SMD jumper
    - Fix position of the LEDs resistor for compatibility with resistors array
    - Fix some silkscreen labels
    [MainBoard.brd, MainBoard.sch]
2019-07-02 ele: MainBoard - Add back project MainBoard (to folder v1.3) after merge
    - Add back project MainBoard (to folder v1.3) after merge with master
    [MainBoard.brd, MainBoard.sch]
2019-07-02 ele: MainBoard - Add version v1.4 and restore version v1.2 after merge
    [MainBoard.brd, MainBoard.sch]
2019-07-03 ele: UIboard - version 1.0
    - Add board as user interface (UI) for controlling the robot
    when the RBControl MainBoard is closed in the robot.
    [UIboard.brd, UIboard.sch]
2019-07-03 ele: UIboard - version 1.1
    - Fix pinout of connectors - make correct order of pins/signals
    due to the cable and pruning connector
    [UIboard.brd, UIboard.sch]
2019-07-03 ele: battery - tuning
    - Fix slot shift in banana pin guide
    - Fix butterfly slot position
    - Update battery panels
    [banana_holder_panel.kicad_pcb, battery.kicad_pcb, bottom_panel.kicad_pcb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]
2019-12-29 ele: Remove potential short-circuit in battery, start v0.5
    [banana_holder_panel.kicad_pcb, battery.kicad_pcb, battery.sch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]
